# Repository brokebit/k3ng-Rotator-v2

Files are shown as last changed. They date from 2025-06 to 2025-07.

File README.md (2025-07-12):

# K3NG Rotator Controller

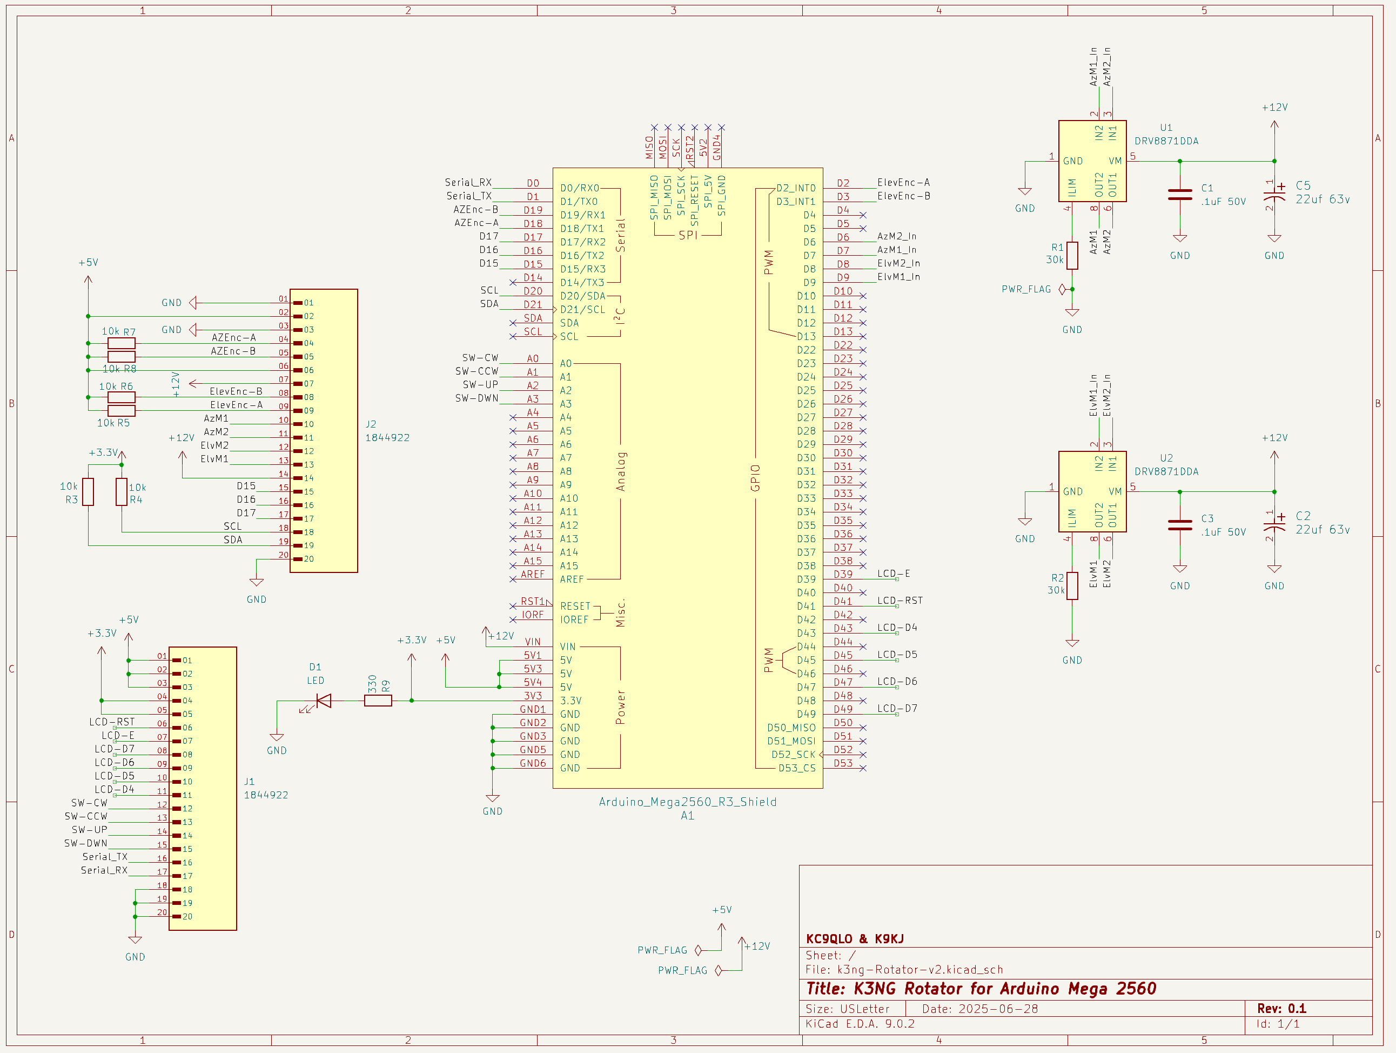
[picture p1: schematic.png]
Schematic

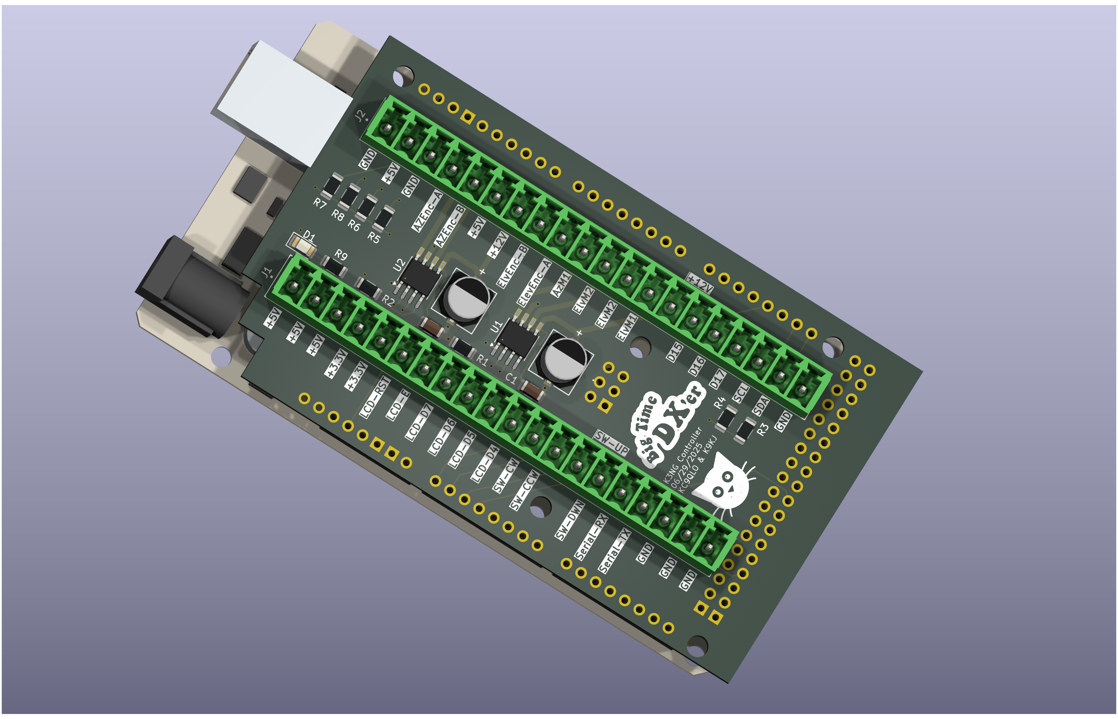
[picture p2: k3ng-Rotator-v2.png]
3D Render


# LCD2004 Connection
**LCD Pin -> Rotator Pin**
1. 1 (GND) -> GND
2. 2 (VCC) -> +5V
3. 3 (Contrast) -> Center Pin (2) of Contrast Potentiometer
4. 4 (Register Select) -> LCD_RST
5. 5 (Read/Write) -> GND
6. 6 (Enable) -> LCD_EN
7. 7 (Data 0) -> NC
8. 8 (Data 1) -> NC
9. 9 (Data 2) -> NC
10. 10 (Data 3) -> NC
11. 11 (Data 4) -> LCD_D4
12. 12 (Data 5) -> LCD_D5
13. 13 (Data 6) -> LCD_D6
14. 14 (Data 7) -> LCD_D7
15. 15 (Backlight +) -> +5V + Contrast Potentiometer Pin 1
16. 16 (Backlight -) -> GND + Contrast Potentiometer Pin 3

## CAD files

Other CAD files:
Manufacture/k3ng-Rotator-v2-F_Paste.dxf

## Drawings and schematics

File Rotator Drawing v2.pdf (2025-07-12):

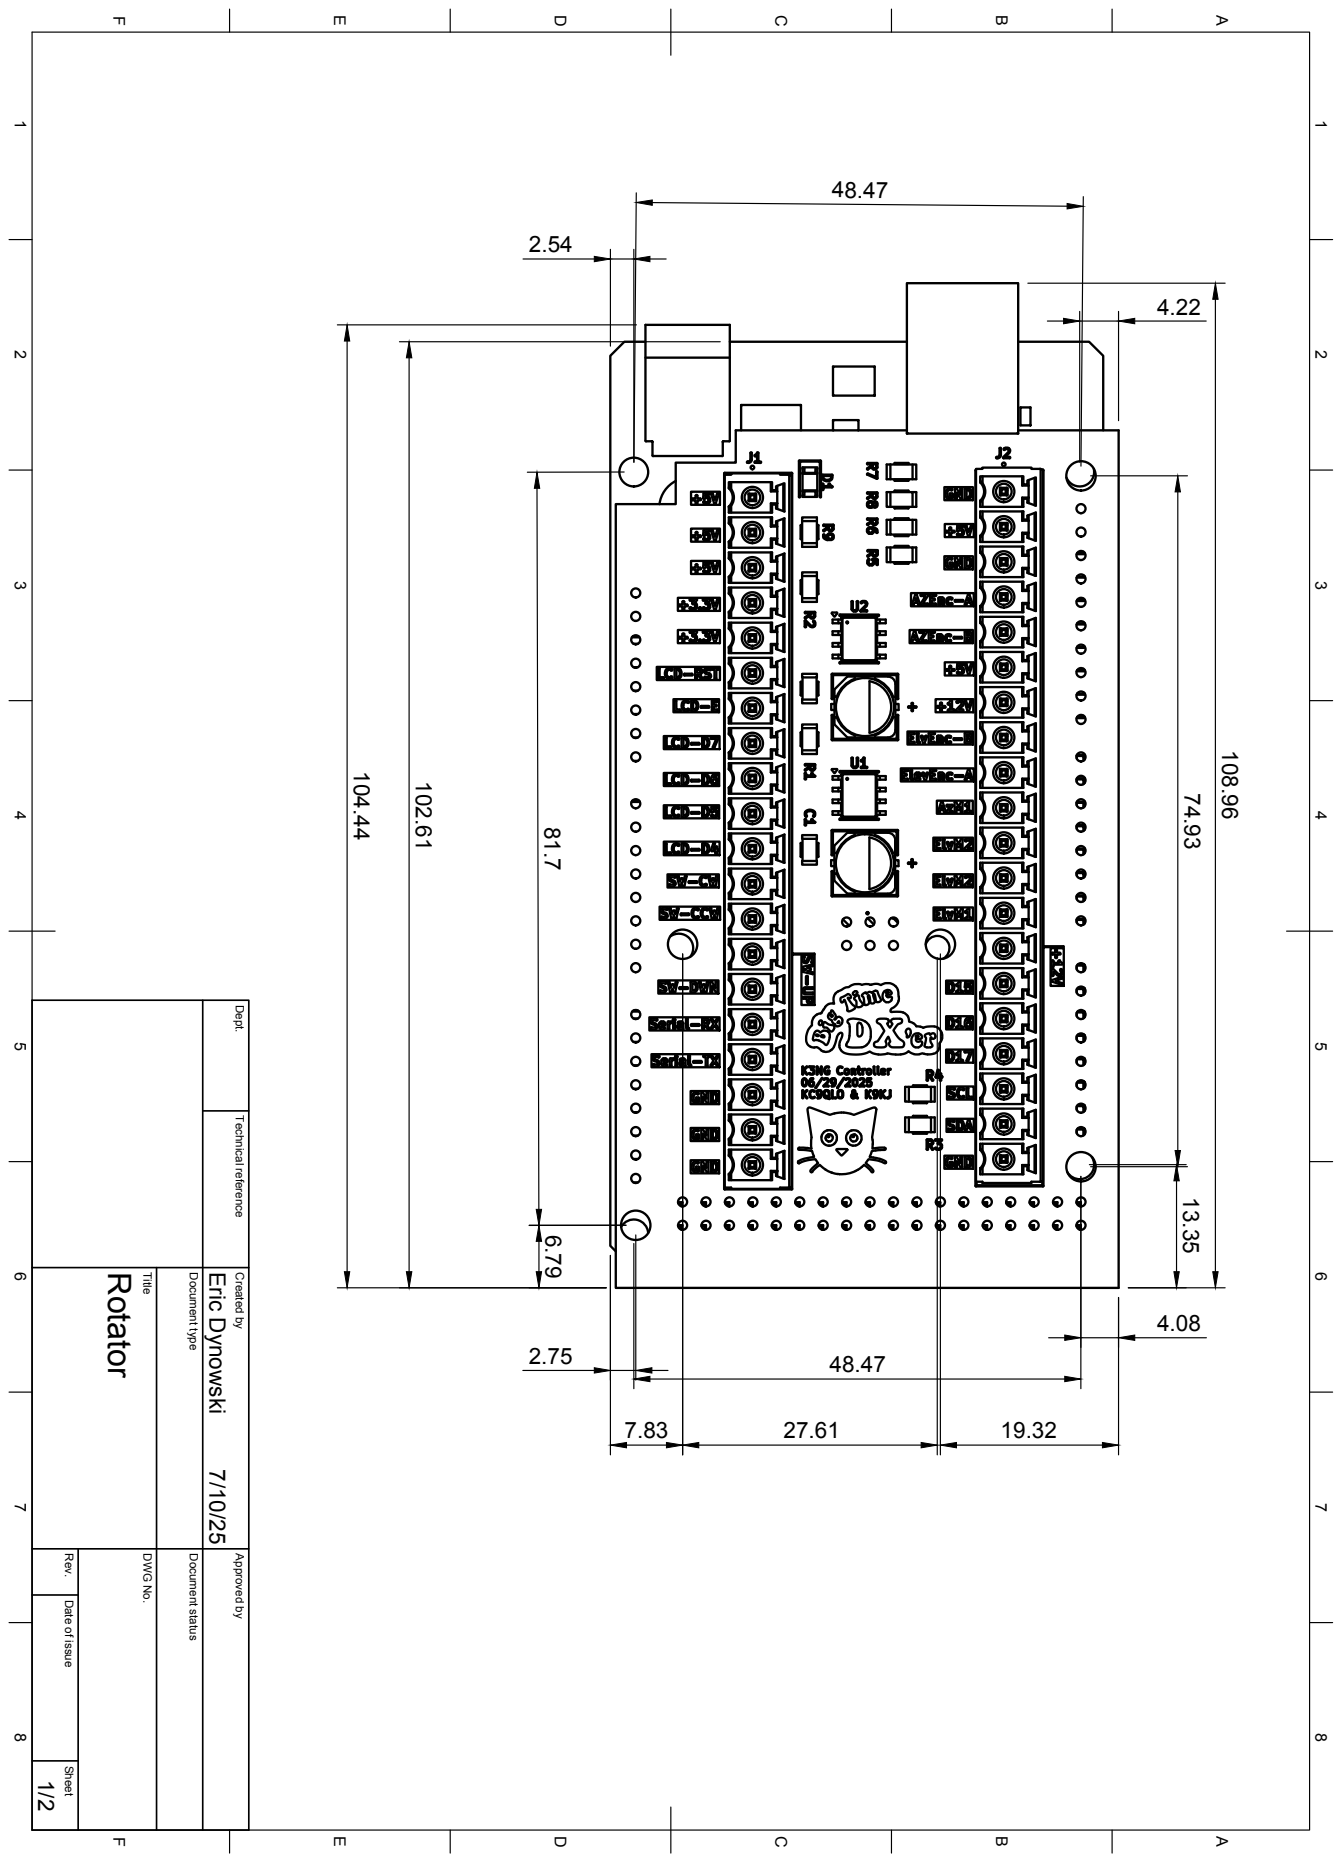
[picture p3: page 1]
DWG No.; Eric Dynowski

Dept. Technical reference Created by Approved by

Document type Document status

Date of issue Sheet

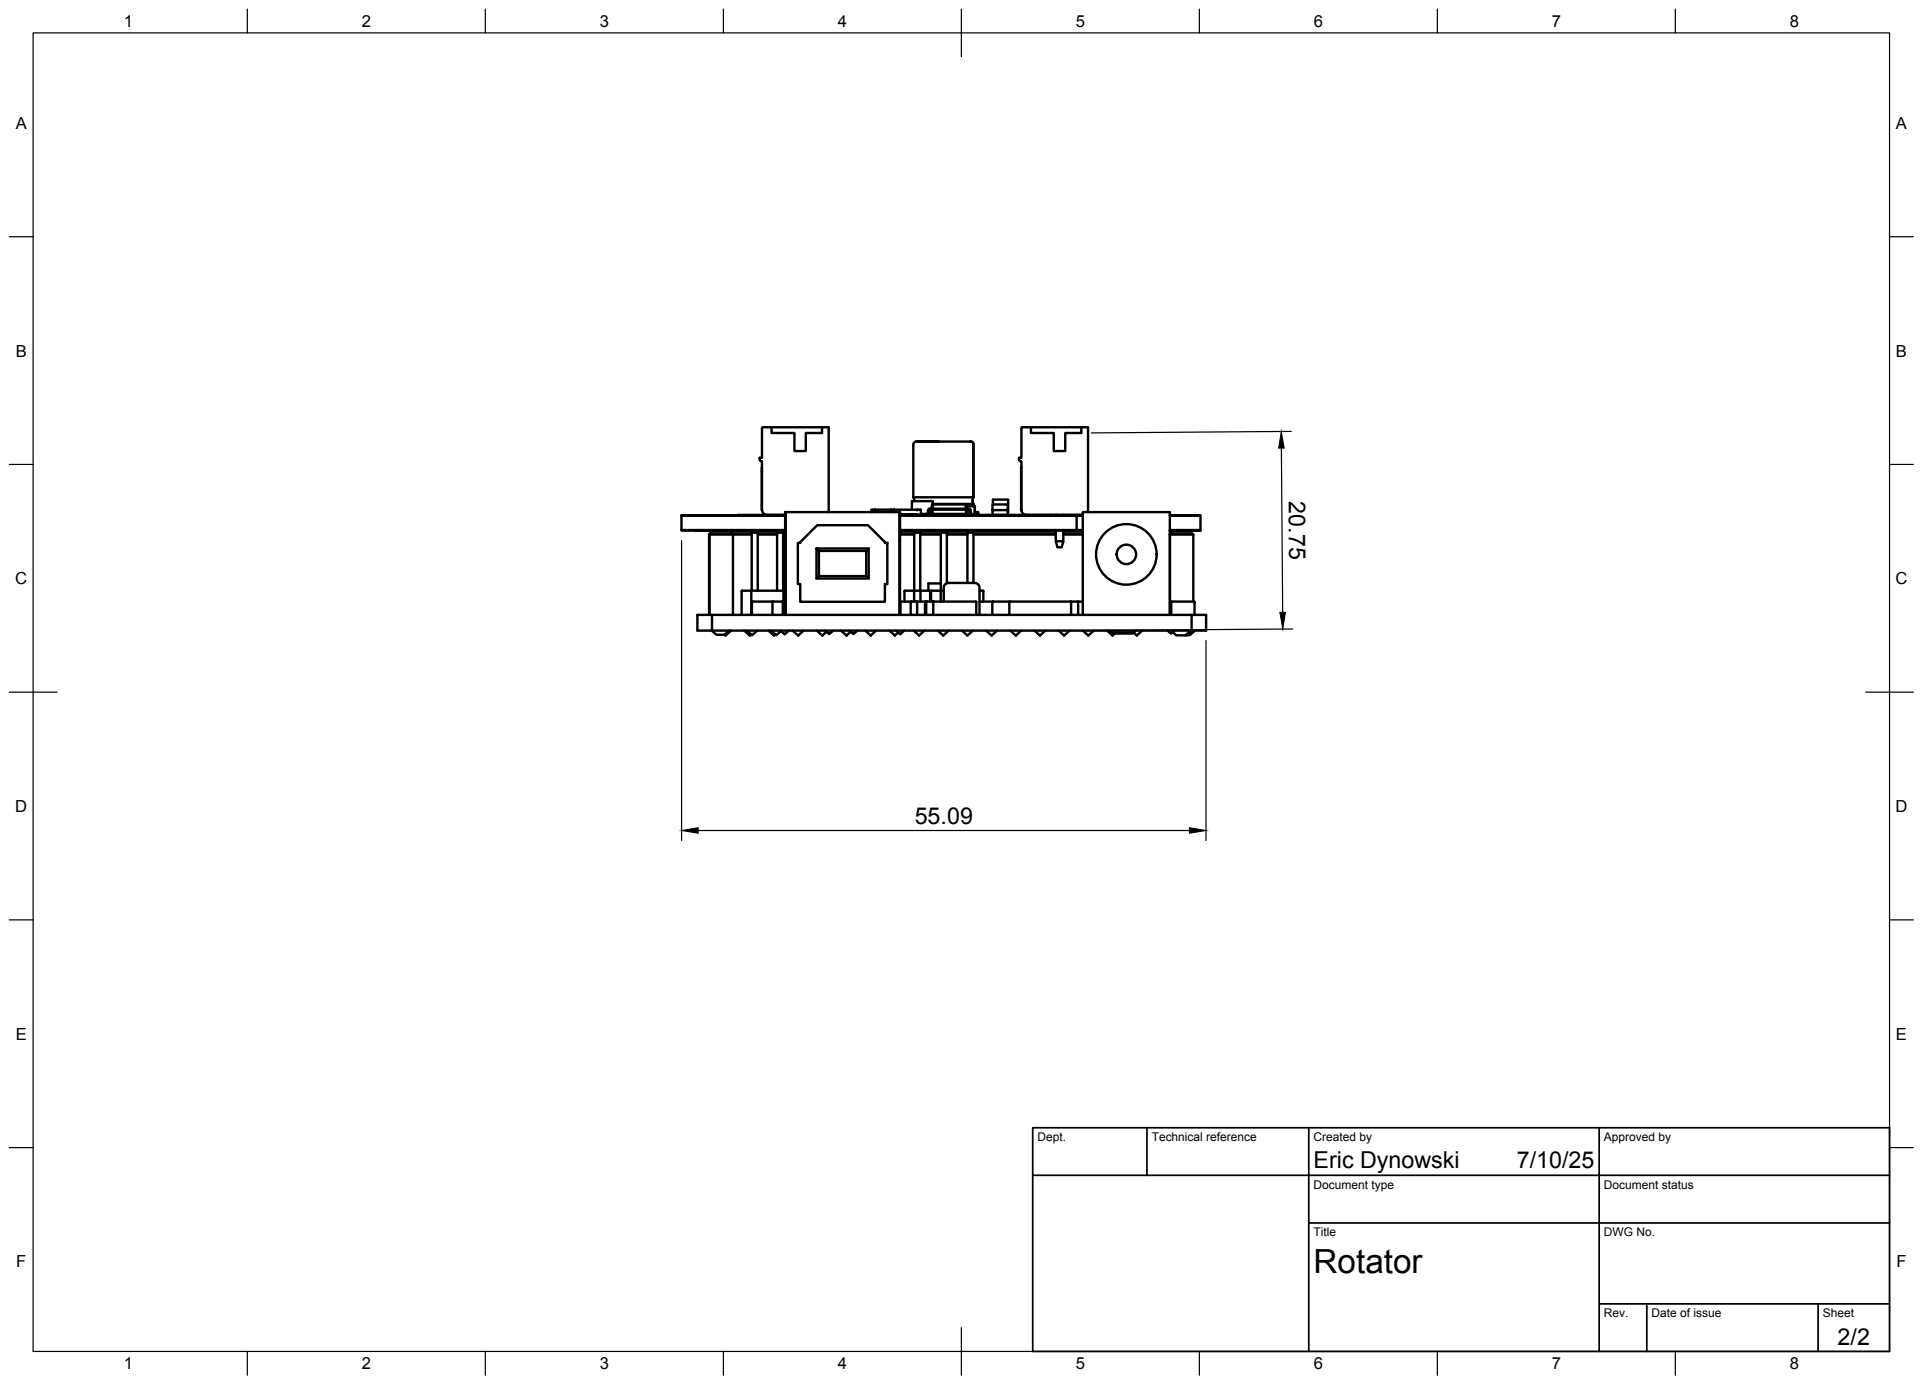
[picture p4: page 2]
Title; DWG No.; Rev.; Date of issue; Sheet; Eric Dynowski 20.75

Dept. | Technical reference | Created by 7/10/25 | Approved by

Document type | Document status

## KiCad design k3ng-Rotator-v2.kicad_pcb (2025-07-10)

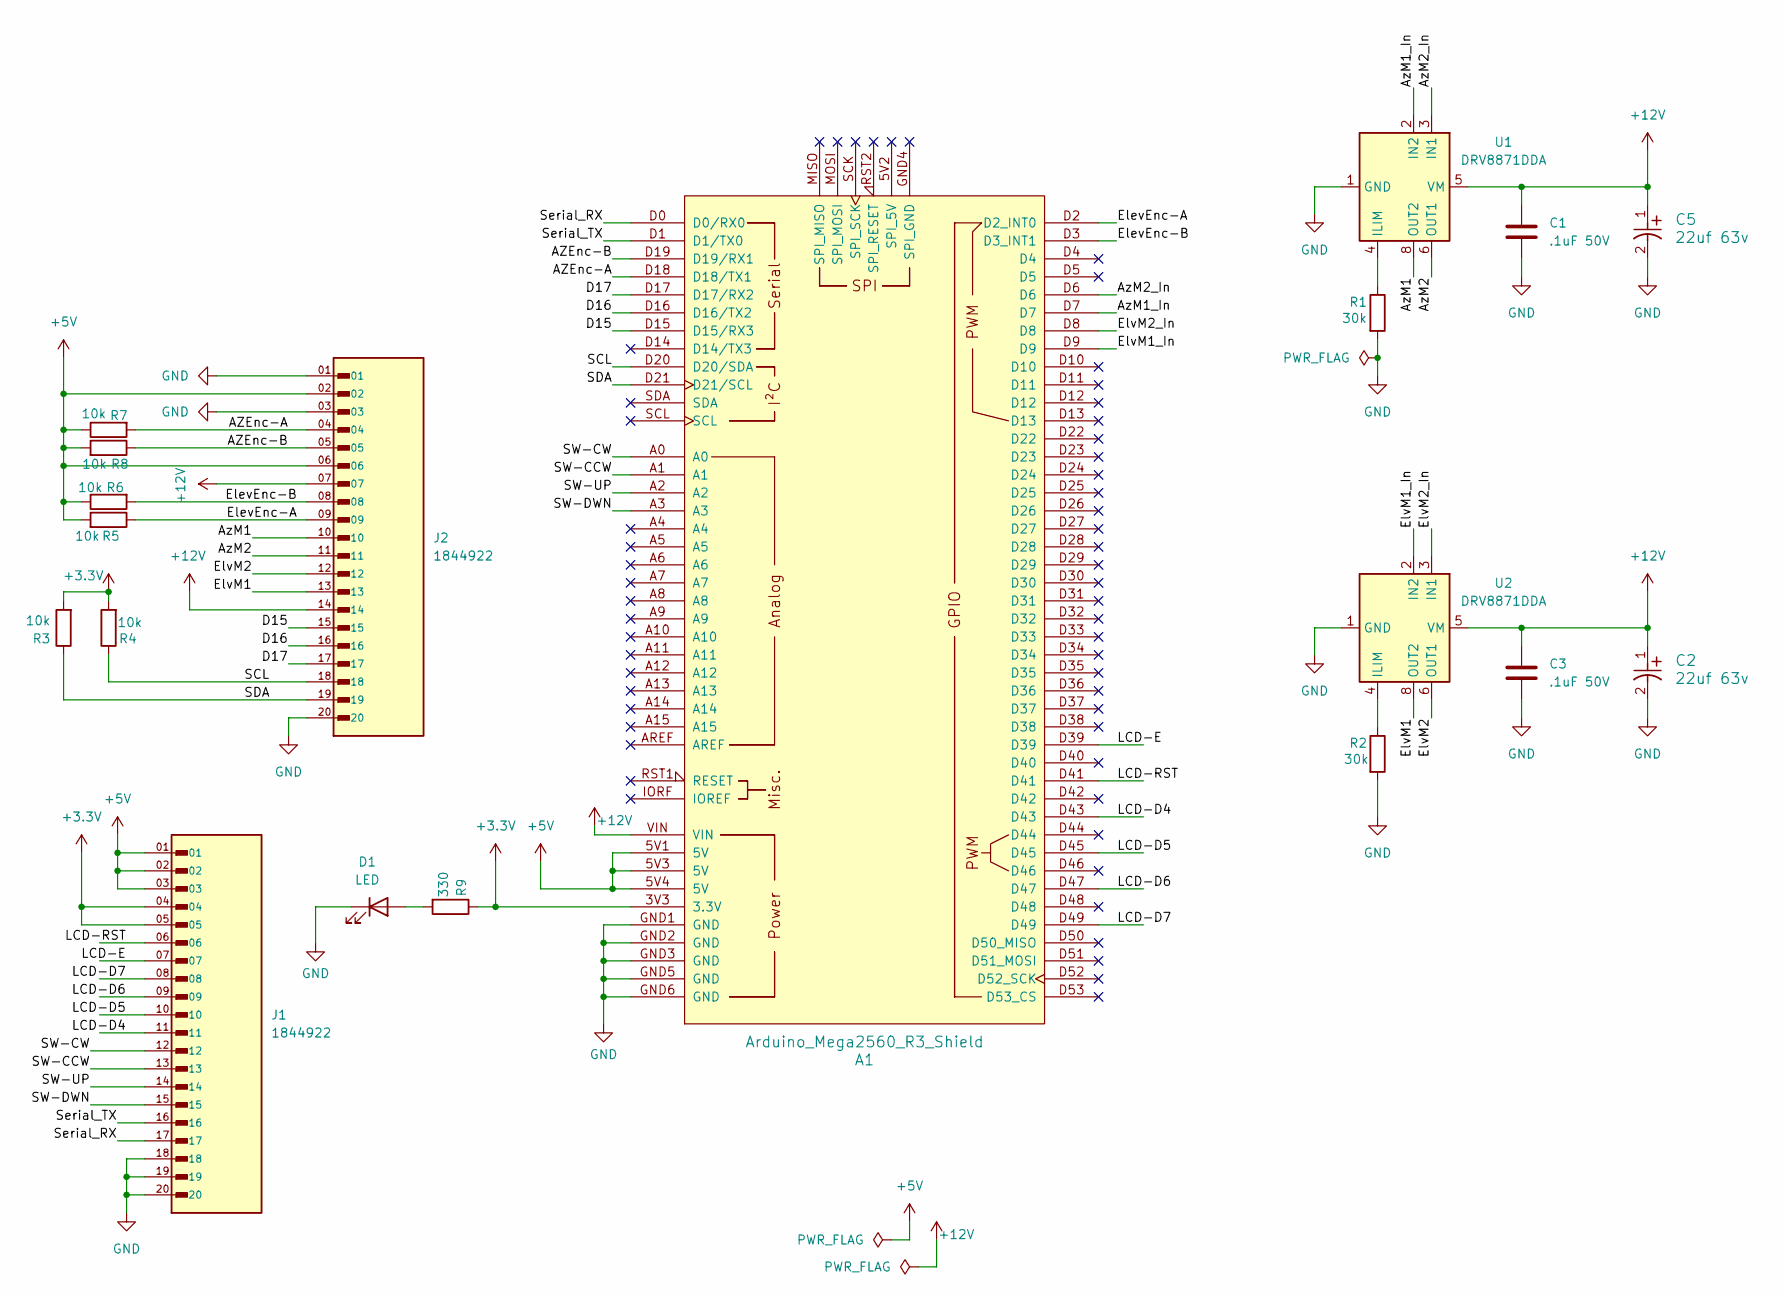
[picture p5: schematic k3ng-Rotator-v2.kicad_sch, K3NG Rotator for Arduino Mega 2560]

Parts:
A1: Arduino_Mega2560_R3_Shield
C1, C3: .1uF 50V; C_1206_3216Metric
C2, C5: 22uf 63v; PCAP_EEHZ_D8_PAN
D1: LED; LED_1206_3216Metric
J1, J2: 1844922; PHOENIX_1844922; PARTREV 25.02.2015
R1, R2: 30k; R_1206_3216Metric
R3, R4, R5, R6, R7, R8: 10k; R_1206_3216Metric
R9: 330; R_1206_3216Metric
U1, U2: DRV8871DDA; Texas_HTSOP-8-1EP_3.9x4.9mm_P1.27mm_EP2.95x4.9mm_Mask2.4x3.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

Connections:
+3.3V: A1.3V3 (3.3V), J1.04, J1.05, R3.2, R4.2, R9.1
+5V: A1.5V1 (5V), A1.5V3 (5V), A1.5V4 (5V), J1.01, J1.02, J1.03, J2.02, J2.06, R5.2, R6.1, R7.1, R8.2
+12V: A1.VIN, C1.1, C2.1, C3.1, C5.1, J2.07, J2.14, U1.5 (VM), U2.5 (VM)
/AZEnc-A: A1.D18 (D18/TX1), J2.04, R7.2
/AZEnc-B: A1.D19 (D19/RX1), J2.05, R8.1
/AzM1: J2.10, U1.8 (OUT2)
/AzM1_In: A1.D7, U1.2 (IN2)
/AzM2: J2.11, U1.6 (OUT1)
/AzM2_In: A1.D6, U1.3 (IN1)
/D15: A1.D15 (D15/RX3), J2.15
/D16: A1.D16 (D16/TX2), J2.16
/D17: A1.D17 (D17/RX2), J2.17
/ElevEnc-A: A1.D2 (D2_INT0), J2.09, R5.1
/ElevEnc-B: A1.D3 (D3_INT1), J2.08, R6.2
/ElvM1: J2.13, U2.8 (OUT2)
/ElvM1_In: A1.D9, U2.2 (IN2)
/ElvM2: J2.12, U2.6 (OUT1)
/ElvM2_In: A1.D8, U2.3 (IN1)
/LCD-D4: A1.D43, J1.11
/LCD-D5: A1.D45, J1.10
/LCD-D6: A1.D47, J1.09
/LCD-D7: A1.D49, J1.08
/LCD-E: A1.D39, J1.07
/LCD-RST: A1.D41, J1.06
/SCL: A1.D20 (D20/SDA), J2.18, R4.1
/SDA: A1.D21 (D21/SCL), J2.19, R3.1
/SW-CCW: A1.A1, J1.13
/SW-CW: A1.A0, J1.12
/SW-DWN: A1.A3, J1.15
/SW-UP: A1.A2, J1.14
/Serial_RX: A1.D0 (D0/RX0), J1.17
/Serial_TX: A1.D1 (D1/TX0), J1.16
GND: A1.GND1 (GND), A1.GND2 (GND), A1.GND3 (GND), A1.GND5 (GND), A1.GND6 (GND), C1.2, C2.2, C3.2, C5.2, D1.1 (K), J1.18, J1.19, J1.20, J2.01, J2.03, J2.20, R1.2, R2.2, U1.1 (GND), U1.7 (GND), U1.9 (GND), U2.1 (GND), U2.7 (GND), U2.9 (GND)
unnamed: D1.2 (A), R9.2
unnamed: R1.1, U1.4 (ILIM)
unnamed: R2.1, U2.4 (ILIM)

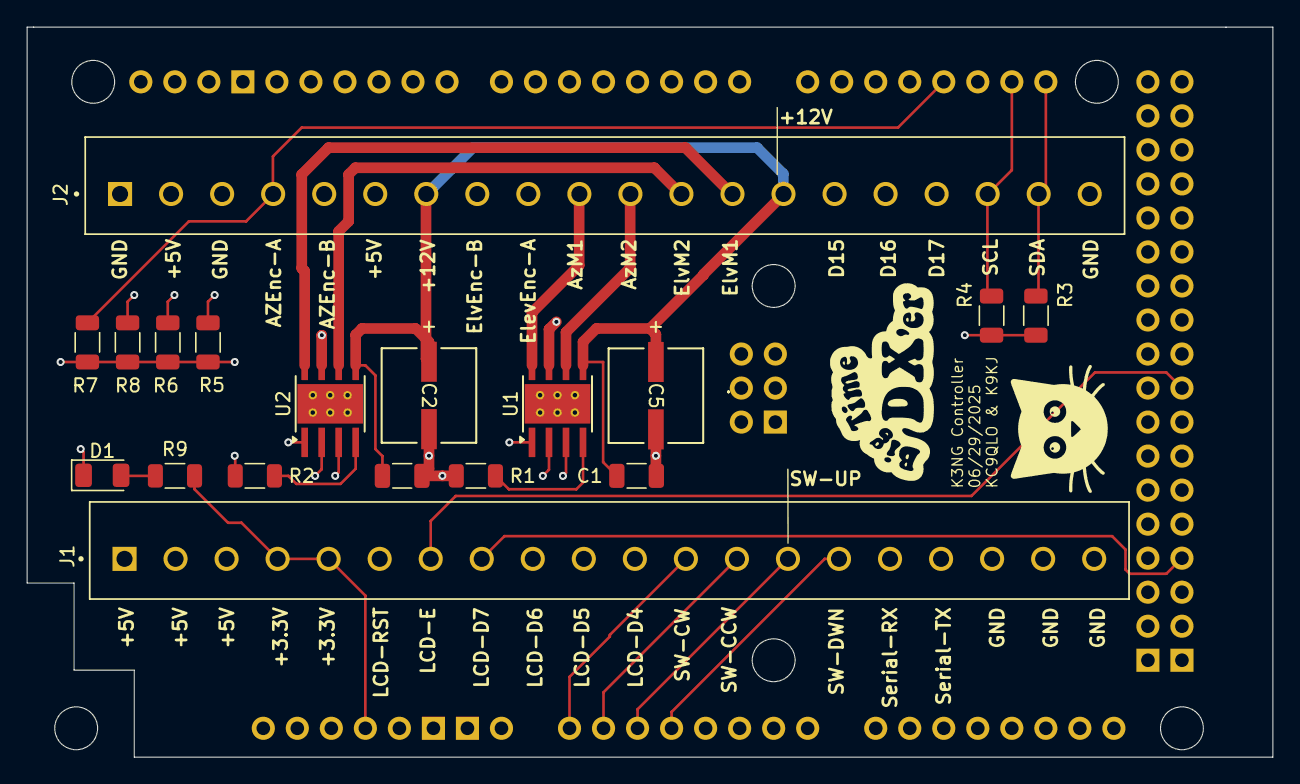
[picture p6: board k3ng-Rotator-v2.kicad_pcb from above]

Board: 6 copper layers, 93.0 x 54.5 mm, 19 parts (0 on the bottom side), 36 nets.
